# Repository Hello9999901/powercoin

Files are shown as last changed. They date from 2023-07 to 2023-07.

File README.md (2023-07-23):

# powercoin

Powercoin is an ultra-compact Qi-certified wireless power transfer receiver. A functional prototype was achieved in May 2022, and full integration into devices like the Logitech G502 or similar Razer products are planned. Optimized for production with JLCPCB.

powercoin render in blender
> _Blender animated render of the powercoin (EEVEE rendering engine, custom procedural materials)_

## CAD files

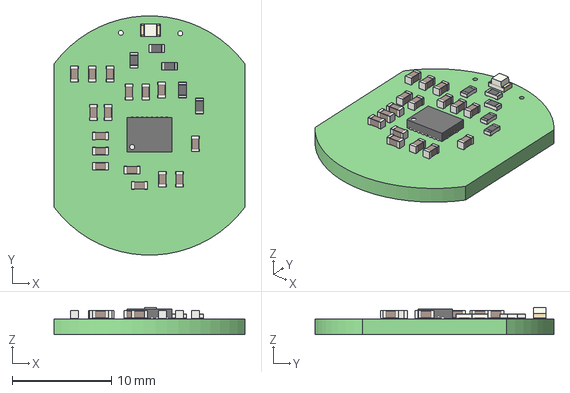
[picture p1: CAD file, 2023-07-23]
powercoin/powercoin.step
19.2 x 24.1 x 2.75 mm
powercoin PCB

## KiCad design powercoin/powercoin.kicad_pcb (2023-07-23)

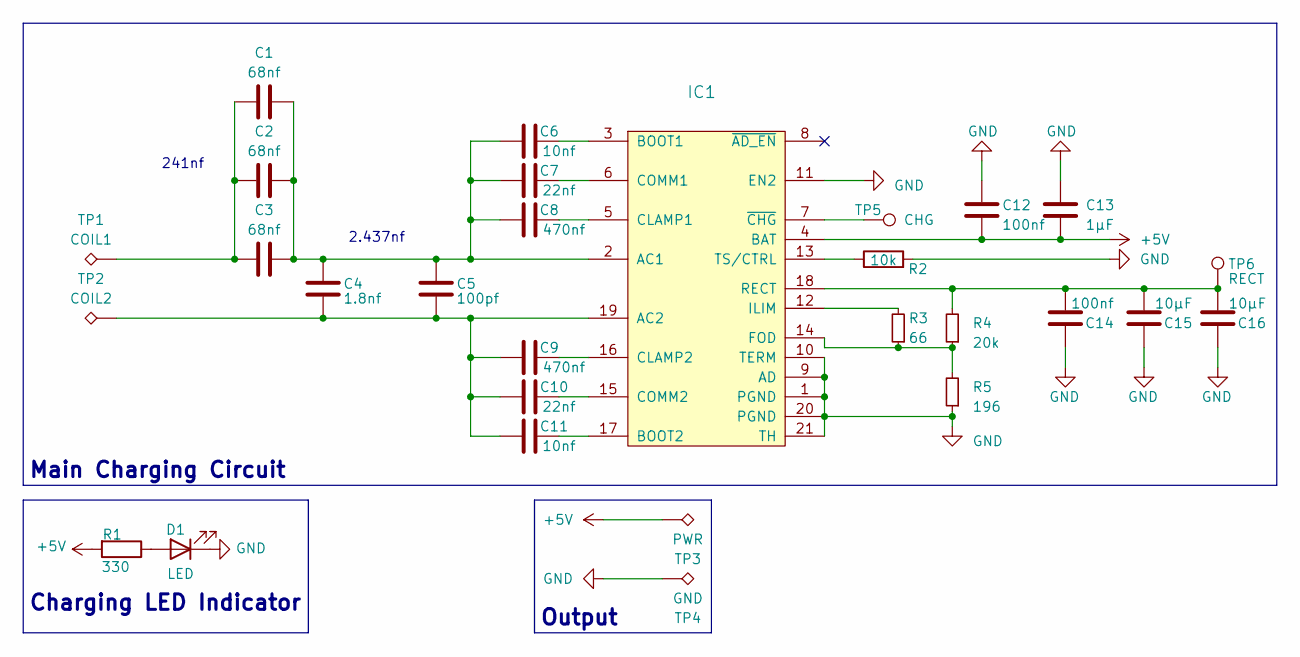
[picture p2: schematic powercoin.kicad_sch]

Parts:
C1, C2, C3: 68nf; C_0603_1608Metric; LCSC C107098
C4: 1.8nf; C_0603_1608Metric; LCSC C318642
C5: 100pf; C_0603_1608Metric; LCSC C14858
C6, C11: 10nf; C_0603_1608Metric; LCSC C100042
C7, C10: 22nf; C_0603_1608Metric; LCSC C21122
C8, C9: 470nf; C_0603_1608Metric; LCSC C1620
C12, C14: 100nf; C_0603_1608Metric; LCSC C14663
C13: 1μF; C_0603_1608Metric; LCSC C1592
C15, C16: 10μF; C_0603_1608Metric; LCSC C85713
D1: LED; LED_0805_2012Metric; LCSC C965818
IC1: Texas_VQFN-RHL-20; MPN BQ51050BRHLR; LCSC C55663
R1: 330; R_0603_1608Metric; LCSC C23138
R2: 10k; R_0603_1608Metric; LCSC C99198
R3: 66; R_0603_1608Metric; LCSC C245056
R4: 20k; R_0603_1608Metric; LCSC C4184
R5: 196; R_0603_1608Metric; LCSC C22899
TP1: COIL1; TestPoint_Keystone_5019_Minature
TP2: COIL2; TestPoint_Keystone_5019_Minature
TP3: PWR; TestPoint_Keystone_5019_Minature
TP4: GND; TestPoint_Keystone_5019_Minature
TP5: CHG; TestPoint_THTPad_D1.0mm_Drill0.5mm
TP6: RECT; TestPoint_THTPad_D1.0mm_Drill0.5mm

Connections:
+5V: C12.1, C13.1, IC1.4 (BAT), R1.2, TP3.1
GND: C12.2, C13.2, C14.2, C15.2, C16.2, D1.1 (K), IC1.1 (PGND), IC1.9 (AD), IC1.10 (TERM), IC1.11 (EN2), IC1.20 (PGND), IC1.21 (TH), R2.2, R5.1, TP4.1
unnamed: C1.1, C2.1, C3.1, TP1.1
unnamed: D1.2 (A), R1.1
unnamed: C1.2, C2.2, C3.2, C4.2, C5.2, C6.1, C7.1, C8.1, IC1.2 (AC1)
unnamed: C4.1, C5.1, C9.1, C10.1, C11.1, IC1.19 (AC2), TP2.1
unnamed: C6.2, IC1.3 (BOOT1)
unnamed: C11.2, IC1.17 (BOOT2)
unnamed: C8.2, IC1.5 (CLAMP1)
unnamed: C9.2, IC1.16 (CLAMP2)
unnamed: C7.2, IC1.6 (COMM1)
unnamed: C10.2, IC1.15 (COMM2)
unnamed: IC1.14 (FOD), R3.1, R4.1, R5.2
unnamed: IC1.12 (ILIM), R3.2
unnamed: C14.1, C15.1, C16.1, IC1.18 (RECT), R4.2, TP6.1
unnamed: IC1.13 (TS/CTRL), R2.1
unnamed: IC1.7 (~CHG), TP5.1

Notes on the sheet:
Output
2.437nf
Main Charging Circuit
241nf
Charging LED Indicator

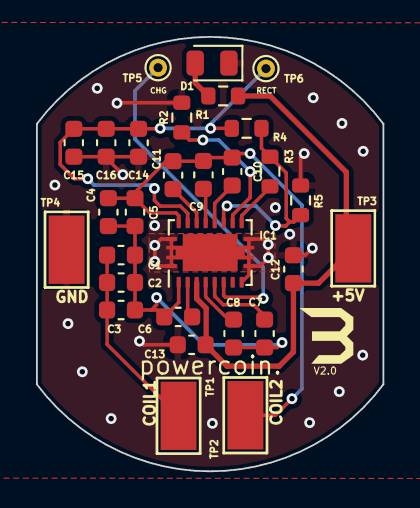
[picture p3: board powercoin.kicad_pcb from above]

Board: 2 copper layers, 19.2 x 24.1 mm, 29 parts (0 on the bottom side), 17 nets.
